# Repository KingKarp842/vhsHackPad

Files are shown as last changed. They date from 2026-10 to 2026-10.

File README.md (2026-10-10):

# vhsHackPad

This project took me around 30 hours total. It was definitely not a straight line from idea to finished macropad, but that was kind of the point. I wanted to make something more advanced than my previous macropad, and vhsHackPad ended up being a mix of PCB design, CAD, firmware, artwork, and a lot of fixing small problems that turned into bigger problems.

## Project Desc.
vhsHackPad is a custom macropad I made for VHS Hack Club. It uses a custom RP2040-based PCB, mechanical keyboard switches, USB-C, and a custom 3D printed enclosure. Instead of using a separate development board, I put the RP2040 and all the supporting parts directly onto the PCB, which made the board thinner and feel more like a real finished device.

I also wanted the PCB to be part of the design instead of something hidden inside the case. The board has custom silkscreen artwork and branding like "vhsHackPad," "Designed by Preston Nguyen," and "Made For VHS Hack Club." I also experimented with exposed ENIG/gold artwork so some of the art would show up as shiny gold on the finished PCB.

The enclosure was designed around the PCB and switches, with a slide-in style case instead of a bunch of screws. That part sounded simple at first, but the tolerances and tabs ended up taking multiple versions before they felt reasonable.

## Main Features
- Custom RP2040 PCB
- USB-C
- Mechanical keyboard switches
- Programmable macropad firmware
- Custom PCB artwork/silkscreen
- Exposed ENIG/gold decorative PCB features
- Custom CAD enclosure
- Slide-in enclosure/tabs
- 3D printed on a Bambu Lab P1S
- Designed specifically for VHS Hack Club
- JLCPCB/JLCPCB assembly-compatible PCB design

## Creation Process
1. Initial Idea & Planning
- I started vhsHackPad because I wanted to make a custom macropad specifically for VHS Hack Club. I had already made a macropad before using a XIAO RP2040, so this time I wanted to level it up by putting the RP2040 directly onto my own PCB. I also wanted the board to actually look cool and show the Hack Club/maker side of the project, not just be a plain circuit board hidden under keycaps.

2. Designing the Schematic
- I started the electronics in KiCad. I added the RP2040, USB-C, power circuitry, crystal, switches, and all the smaller supporting components that the RP2040 needs. Since I was not using a dev board this time, I had to actually understand how the chip was wired instead of just plugging into pins on a premade board.

I also added a GPIO pinout for fun because I had enough room and thought it would be cool if the macropad could technically act kind of like a dev board too, even though I would not really recommend using it that way. One of the harder parts here was figuring out the crystal and some of the RP2040 support circuitry. I had to check which crystal pins were the actual signal pins and which ones needed to be grounded. After fixing that and cleaning up a few other schematic issues, I could finally move on to the PCB layout.

vhsHackPad SCHEMATIC

3. PCB Layout & Routing
- The PCB layout was probably one of the biggest parts of the whole project. I had to place the switches, USB-C port, RP2040, flash, crystal, power parts, and a bunch of tiny components on a board that I still wanted to keep compact.

At first I kept moving the MCU around because every placement seemed to fix one problem and create another one. If the RP2040 was in one spot, the USB routing was easier but the switch traces were worse. If I moved it somewhere else, the support components fit better but routing got messy again. I probably moved the MCU back and forth way more times than I expected.

This was also my first time working with an embedded MCU directly on a board, so I had to research where the supporting components should go relative to the chip. The crystal and decoupling capacitors could not just be thrown anywhere. I had to think about keeping important parts close while still making room for the switches and artwork.

Routing was dense because there were a lot of parts fighting for space on a small board. I went through DRC multiple times while fixing clearance problems, routing issues, and unconnected pads. Eventually, I got the actual electrical design down to 0 unconnected pads, 0 footprint errors, and 0 electrical clearance violations. The remaining warnings were mostly silkscreen-related instead of real electrical problems.

vhshackpadMCU

Figuring out how to route all the parts to the MCU properly

vhsHackPadRouting

Finished Routing

vhsHackPad-nosilk

3D Render

4. Custom PCB Artwork
- I did not want the PCB to just look like a normal circuit board, so I spent a good amount of time adding custom artwork and branding. I added vhsHackPad, Designed by Preston Nguyen, Made For VHS Hack Club, the board version/date, and a bunch of Orpheus art that looked really good on the render.

The exposed copper/ENIG art was also a learning thing. I had to figure out how copper, solder mask openings, and silkscreen all interacted. Some details that looked fine on screen were too tiny to manufacture cleanly, so I had to simplify parts of the artwork and make sure it would still look decent on the real PCB.
vhsHackPadCOPPERFLAG

Copper flag art

vhsHackPad PCB

Orpheus (Hack Club Mascot) silk art!

vhsHackPad M B

3D Render w/ Silk

5. Preparing the PCB for Manufacturing
- While designing the board, I kept manufacturing and assembly in mind. I checked components and tried to pick parts that would keep the PCB reasonably inexpensive and compatible with economical PCB assembly instead of making the board way more expensive than it needed to be.

I also checked the final PCB for errors before calling it ready. This was important because once the board is manufactured, a small mistake can turn into a much more annoying problem. I made sure the important electrical issues were fixed before moving forward.
Screenshot 2026-08-14 at 11 58 27 PM

Matching Parts

vhsHackPadJLCBack

vhsHackPadJLCFront

Render of the pcb (obviously in black)

6. Designing the Enclosure
- Once the PCB was mostly finished, I started designing the enclosure. I used measurements from my previous macropad as a starting point because I already had a rough idea of what worked and what did not.

For this version, I made the switch openings around 15.75 mm x 15.75 mm because I did not want the switches to clip in too tightly. I wanted the build to be removable enough that the board could still be accessed. I also had to balance the spacing between the switches and the case edges so it stayed compact without making everything cramped.

7. Fixing Switch & Case Clearances
- Some of the original CAD dimensions looked fine in SolidWorks but were too tight for real 3D printing. That was one of the bigger lessons from the enclosure: if two parts are modeled with basically no tolerance, they are probably not going to slide together nicely after printing.

I had to go back and resize the switch openings, spacing, and walls. The slide-in tabs especially needed adjustments because the first versions were either too tight or just not practical. I went through about 4 versions of the enclosure, changing a measurement, checking what it affected, and then changing nearby features too.

8. Designing the Slide-In Case
- I wanted the enclosure pieces to slide together instead of using a bunch of screws, so I designed small slide-in tabs with matching openings. This ended up being way more annoying than I expected.

Originally, some of the tabs and openings were around 0.60 mm and 0.75 mm, but that was too close for 3D printing. A tab that is the same size as the slot in CAD does not magically fit perfectly in real life. I experimented with smaller tab dimensions, including around 0.45 mm for a 0.60 mm opening, so there would actually be some clearance.

The goal was to make the case tight enough that it would not randomly fall apart, but loose enough that it could still slide together without feeling like I was about to break it. This part took a lot of tiny edits.

A388B26B-A696-4B3C-B306-50D3C65838B8_1_105_c

71BBC9EB-22AC-4D64-BC14-521CB4A789E4_1_105_c

B477437C-3D49-40A2-884D-C89541A27FF9_1_105_c

Solidworks Crashed alot... also lapse didn't work on all of CAD...

9. Iterating the CAD
- A lot of the CAD process was basically fixing one thing and then realizing that the fix affected something else. Changing the tabs affected the nearby walls. Changing wall thickness affected how much space the PCB had. Changing clearances affected whether the slide-in case felt usable.

For example, when I changed dimensions from around 0.75 mm to 0.60 mm, I also had to adjust distances between those features and the walls. It was not just one magic number that fixed everything. I had to keep checking the whole case as one system.

SolidWorks also crashed a lot, which made the process more frustrating because I could not always just smoothly iterate. Still, after enough versions, the enclosure ended up in a much better place than the first model.

A8300315-275C-4646-8056-96588B22744A_1_105_c

Top View of Finished CAD

2E81ADBB-D204-44F5-8050-76056BB91F5F_1_105_c

FINISHED CAD

10. Final Hardware Design
- After the electronics, PCB layout, artwork, enclosure, and tolerance work, I ended up with a complete vhsHackPad design. This was a big step up from my previous macropad because I was no longer building around a premade RP2040 board. I designed the RP2040 electronics into the PCB myself, which made the final build cleaner and more complete.

The manufactured PCB honestly came out really nice, especially the artwork. The enclosure and acrylic were less perfect. I used score-and-snap for the acrylic, and one of the corners did not snap cleanly along the line. The top-left corner ended up looking kind of ugly because I rushed it and did not support/snap it as carefully as I should have. It still works, but it is definitely a visible reminder that the physical build matters just as much as the CAD.

B6525CCC-FC3B-416D-AB25-DD14E9A96C1E_1_105_c

Manufactured PCB! (IT LOOKS SO GOOD YAYY)

528901A4-0872-4D8E-BF5D-6395DE8F3A71_1_102_o

A22F3DD4-4E69-48C5-B66F-BC39F1697796_1_105_c

I was scoring and snapping the acrylic and got lazy so the top left is snapped weird

52E2D442-2B58-433F-9D02-B933B688B8AD_1_105_c

Final Assembled Build

11. Programming the HackPad
- After the hardware was designed, I worked on the firmware that makes the HackPad act like a keyboard. I used CircuitPython with KMK to program the RP2040 and assign actions to the mechanical switches.

This also needed multiple updates instead of working perfectly the first time. I had to make sure the switch pins in the firmware matched the GPIO pins I chose in the PCB design. Since the PCB was custom, the code had to match my actual hardware layout, not some default macropad layout from online.

The firmware is easy to change later, so the keys can be remapped to different shortcuts or functions without changing the hardware. That was one of the reasons I wanted to use KMK/CircuitPython in the first place.

12. Testing & Iterating the Firmware
- Once the firmware was on the board, I tested the switches to make sure each key press was detected and sent the expected keyboard input over USB. Some things needed fixing. One of the main bugs was that the left and right arrow keys were backwards, so pressing the physical left key would act like right, and pressing the right key would act like left.

To fix it, I had to compare the code against the actual PCB pin assignments and key layout, then update the keymap so the physical keys matched what they were supposed to do. I also updated the firmware multiple times while testing different key assignments and making sure the macropad behaved like a normal USB keyboard.

This part reminded me that a PCB can be electrically fine and still need software debugging. The code running is not the same thing as every key doing the correct thing.

Check out the CODE README under the Firmware section!

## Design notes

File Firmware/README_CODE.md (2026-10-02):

# Firmware

The macropad runs on CircuitPython and uses the adafruit_hid library to act like a USB keyboard.
The four switches are connected directly to GPIO pins on the RP2040:
- GPIO2 = Up
- GPIO3 = Left
- GPIO4 = Down
- GPIO5 = Right

By default, the macropad works as a normal arrow-key pad.
It also has a second shortcut mode. To switch modes, press all three bottom keys at the same time, release them, and repeat that 3 times within about 2 seconds.

## Arrow Mode

- Top = Up Arrow
- Bottom Left = Left Arrow
- Bottom Middle = Down Arrow
- Bottom Right = Right Arrow

## Shortcut Mode

- Top = Command + Tab
- Bottom Left = Command + T
- Bottom Middle = Command + V
- Bottom Right = Command + C
Pressing the bottom three keys together 3 times again switches back to arrow mode.

## How the Code Works

Each switch is set up as a digital input with the RP2040's internal pull-up resistor enabled. Because each switch connects the GPIO pin to ground when pressed, the code treats a LOW signal as a key press. The program constantly checks the state of all four switches. When a key changes from released to pressed, it sends the matching keyboard command over USB using adafruit_hid.

The code also watches for the three bottom keys being pressed at the same time. Each completed three-key press counts toward the mode-change sequence. After three of these presses, the firmware switches between arrow mode and shortcut mode.

## Setting Up the Board

The RP2040 first needs CircuitPython installed.
Hold the BOOTSEL button while plugging the board into a computer. The board should appear as a drive called:
RPI-RP2
Download the correct CircuitPython .uf2 file for the RP2040 and copy it onto RPI-RP2.
After the board restarts, it should appear as:
CIRCUITPY

## Installing the HID Library

The firmware uses Adafruit's HID library.
Download the CircuitPython Library Bundle that matches the major version of CircuitPython installed on the board.
From the bundle, copy:
adafruit_hid
into the lib folder on the board.

## Installing the Firmware

Copy the macropad firmware into the root of the CIRCUITPY drive and name it:
code.py

CircuitPython automatically runs code.py whenever the board powers on or the file is saved.
No separate compiler or flashing software is needed after CircuitPython is installed.

The current shortcut layout is made for macOS because it uses the Command key for copy, paste, new tab, and application switching.

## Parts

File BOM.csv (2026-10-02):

Item | Quantity | Description
Custom PCB | 1 | RP2040 macropad PCB with all SMD components assembled
MX-Compatible Keyswitch | 4 | User-installed keyboard switches
Keycaps | 4 | MX-compatible keycaps
Acrylic Bottom | 1 | Clear acrylic bottom panel
3D Printed Case | 1 | Custom enclosure
USB-C Cable | 1 | For power and data

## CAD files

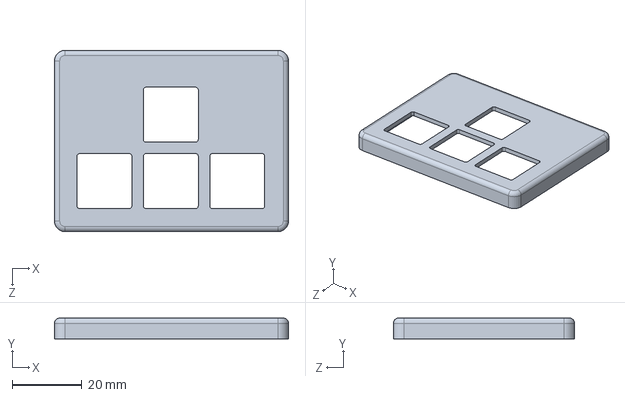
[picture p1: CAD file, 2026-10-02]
CAD Files/SolidWorks/vhsHackPad_Top.SLDPRT
67.1 x 6.00 x 52.0 mm

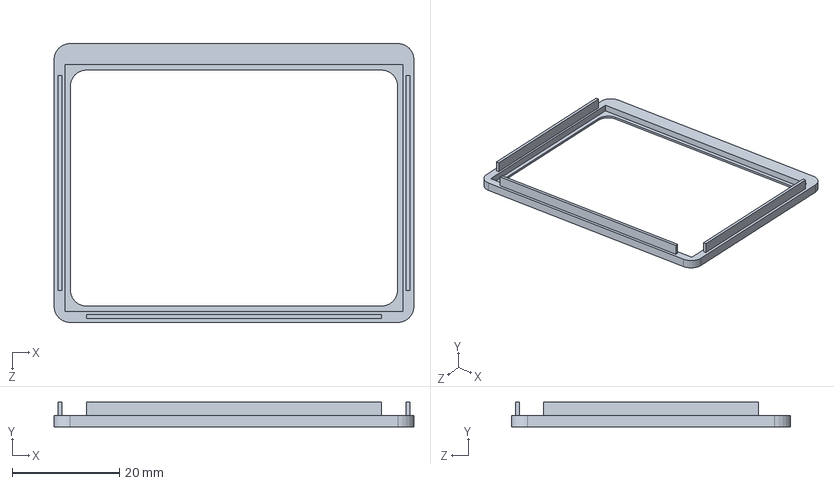
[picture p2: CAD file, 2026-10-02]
CAD Files/SolidWorks/vhsHackPad_Bottom.SLDPRT
67.1 x 4.60 x 52.0 mm

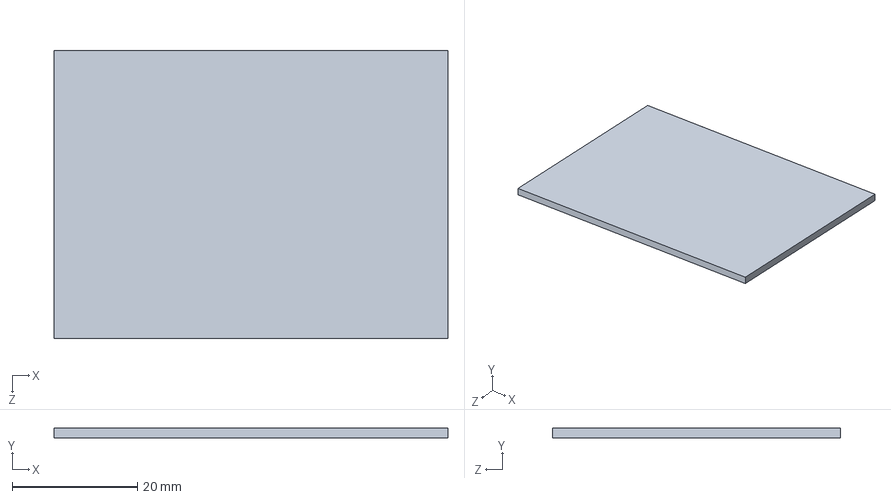
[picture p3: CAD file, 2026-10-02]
CAD Files/SolidWorks/vhsHackPad_Acrylic.SLDPRT
63.0 x 1.60 x 46.0 mm

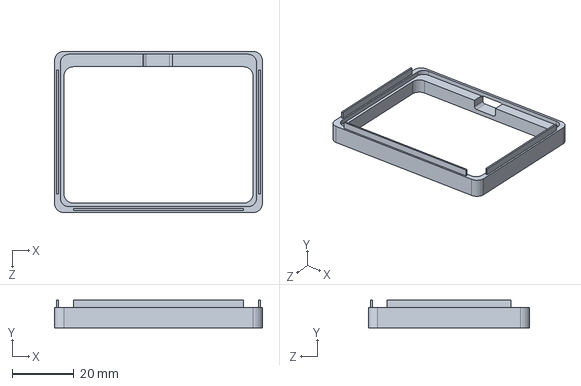
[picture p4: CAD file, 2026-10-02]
CAD Files/SolidWorks/vhsHackPad_Middle.SLDPRT
67.1 x 9.00 x 52.0 mm

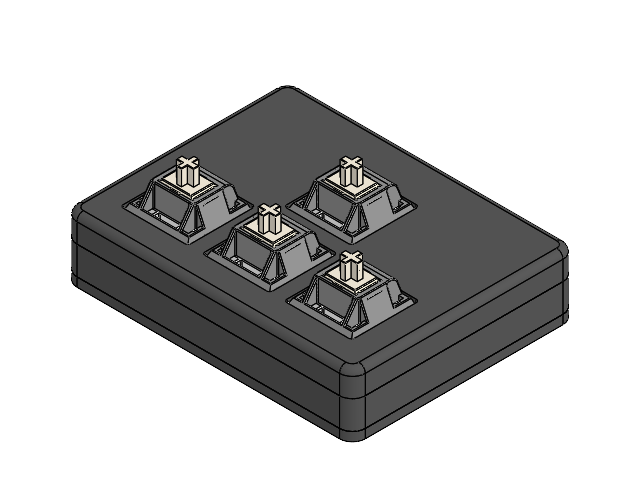
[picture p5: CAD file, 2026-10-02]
CAD Files/SolidWorks/vhsHackPad_Assembly.SLDASM
vhsHackPad_Bottom
vhsHackPad_Middle
vhsHackPad_Top
C_0603_1608Metric-0.step x 17
R_0603_1608Metric-1.step x 6
SW_SPST_TL3305A-2.step x 2
QFN-56-1EP_7x7mm_P0.4mm_EP3.2x3.2mm-3.step
SOIC-8_5.3x5.3mm_P1.27mm-4.step
Crystal_SMD_3225-4Pin_3.2x2.5mm-5.step
SOT-23-5-6.step
vhsHackPad_copper.step
vhsHackPad_silkscreen-7.step
vhsHackPad_soldermask.step
vhsHackPad_soldermask-8.step
vhsHackPad_PCB.step
f69c03da-2874-4e90-9b88-dd8424af37a8.step
vhsHackPad_Acrylic
MX_DOWN.stp x 4
MX_UP.stp x 4
UP_MX.stp x 4
MX_PIN.stp x 4
MX_SPRING.stp x 4
MX_CLICK.stp x 4

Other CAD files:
CAD Files/3MF/vhsHackPad_Bottom.3MF
CAD Files/3MF/vhsHackPad_Middle.3MF
CAD Files/3MF/vhsHackPad_Top.3MF

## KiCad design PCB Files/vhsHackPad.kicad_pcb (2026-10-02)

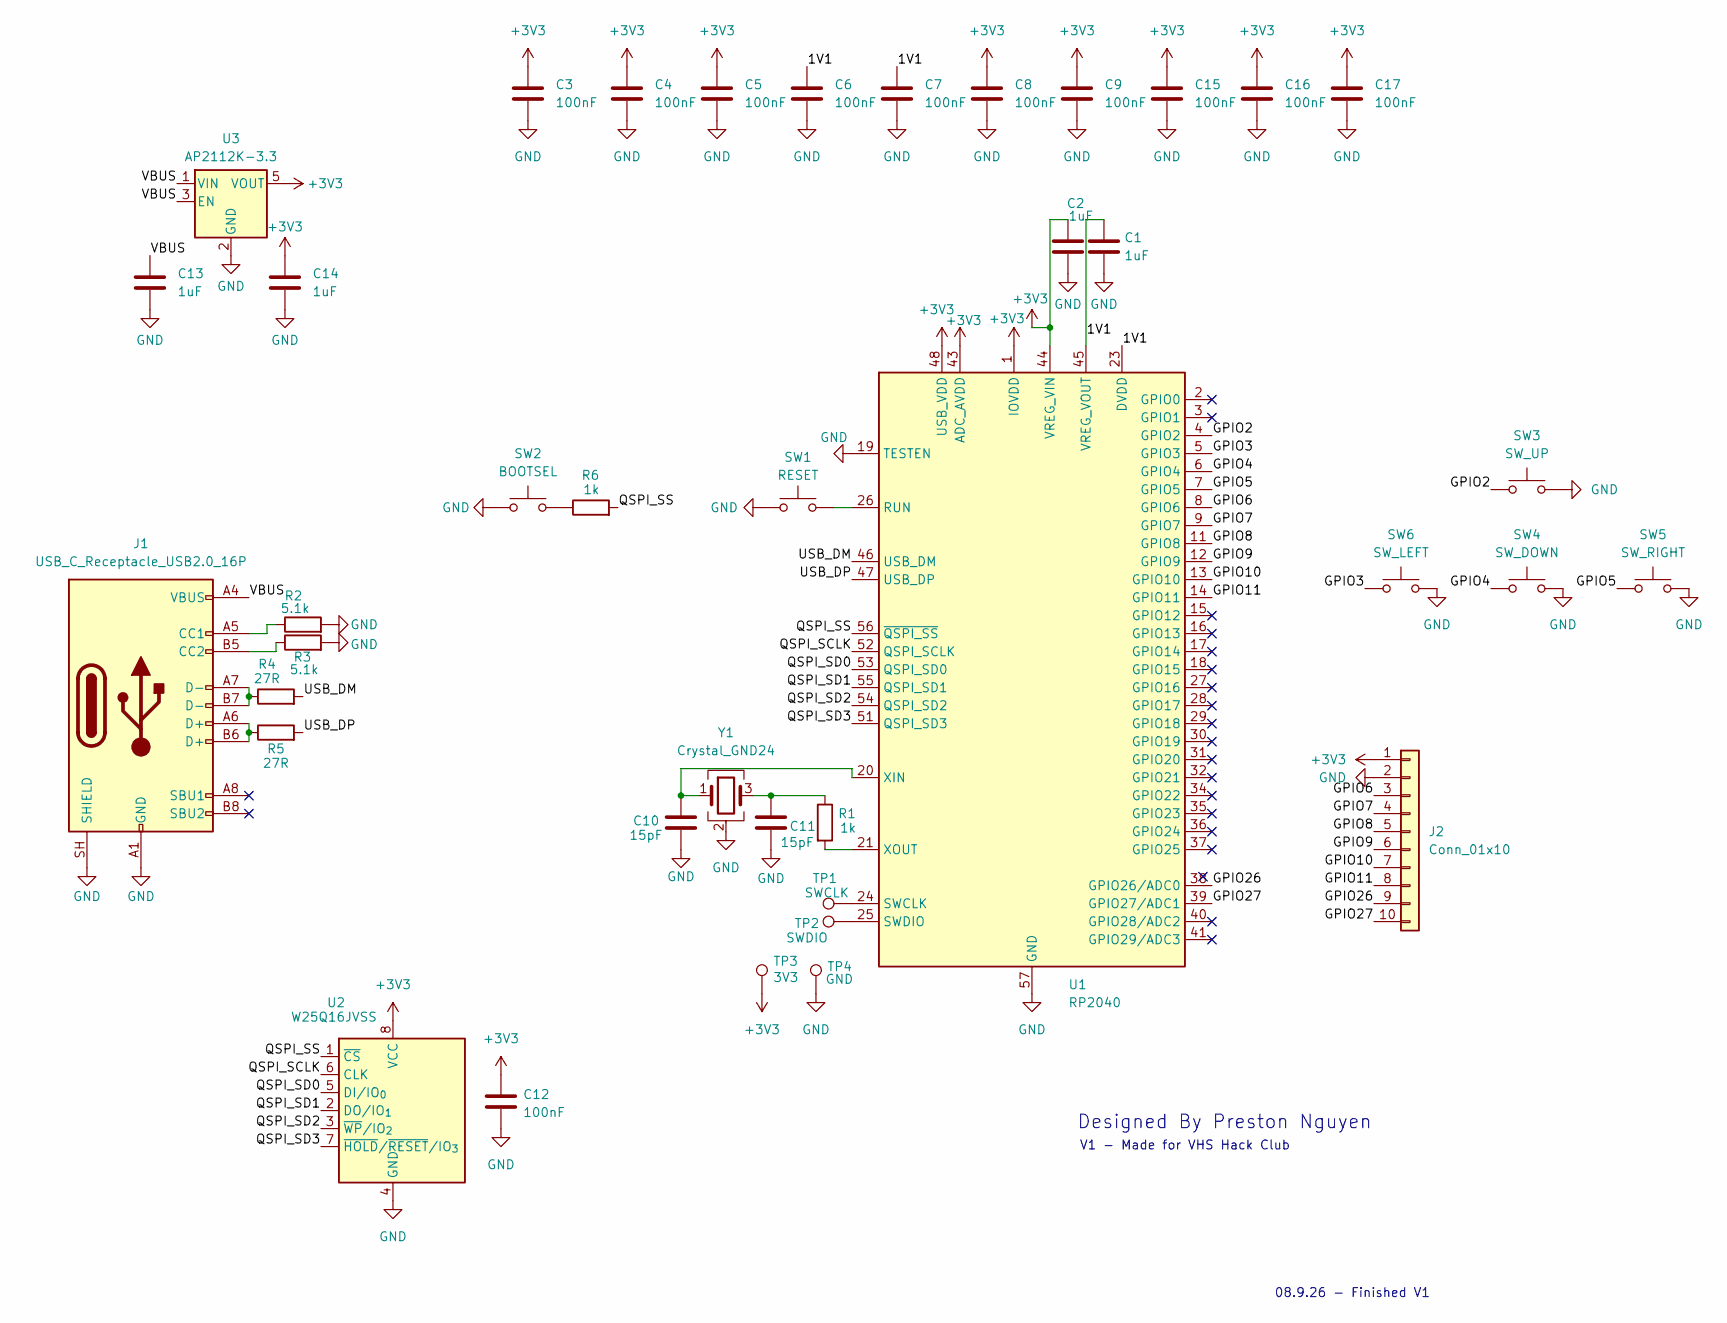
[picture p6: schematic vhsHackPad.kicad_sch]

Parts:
C1, C2, C13, C14: 1uF; C_0603_1608Metric
C3, C4, C5, C6, C7, C8, C9, C12, C15, C16, C17: 100nF; C_0603_1608Metric
C10, C11: 15pF; C_0603_1608Metric
J1: USB_C_Receptacle_USB2.0_16P; USB_C_Receptacle_HRO_TYPE-C-31-M-12
J2: Conn_01x10; PinHeader_1x10_P2.54mm_Vertical
R1, R6: 1k; R_0603_1608Metric
R2, R3: 5.1k; R_0603_1608Metric
R4, R5: 27R; R_0603_1608Metric
SW1: RESET; SW_SPST_TL3305A
SW2: BOOTSEL; SW_SPST_TL3305A
SW3: SW_UP; SW_Cherry_MX_1.00u_PCB
SW4: SW_DOWN; SW_Cherry_MX_1.00u_PCB
SW5: SW_RIGHT; SW_Cherry_MX_1.00u_PCB
SW6: SW_LEFT; SW_Cherry_MX_1.00u_PCB
TP1: SWCLK; TestPoint_Pad_D1.5mm
TP2: SWDIO; TestPoint_Pad_D1.5mm
TP3: 3V3; TestPoint_Pad_D1.5mm
TP4: GND; TestPoint_Pad_D1.5mm
U1: RP2040; QFN-56-1EP_7x7mm_P0.4mm_EP3.2x3.2mm
U2: W25Q16JVSS; SOIC-8_5.3x5.3mm_P1.27mm
U3: AP2112K-3.3; SOT-23-5
Y1: Crystal_GND24; Crystal_SMD_3225-4Pin_3.2x2.5mm

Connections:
+3V3: C2.1, C3.1, C4.1, C5.1, C8.1, C9.1, C12.1, C14.1, C15.1, C16.1, C17.1, J2.1, TP3.1 (1_1), U1.1 (IOVDD), U1.10 (IOVDD), U1.22 (IOVDD), U1.33 (IOVDD), U1.42 (IOVDD), U1.43 (ADC_AVDD), U1.44 (VREG_VIN), U1.48 (USB_VDD), U1.49 (IOVDD), U2.8 (VCC), U3.5 (VOUT)
/1V1: C1.1, C6.1, C7.1, U1.23 (DVDD), U1.45 (VREG_VOUT), U1.50 (DVDD)
/GPIO2: SW3.1, U1.4 (GPIO2)
/GPIO3: SW6.1, U1.5 (GPIO3)
/GPIO4: SW4.1, U1.6 (GPIO4)
/GPIO5: SW5.1, U1.7 (GPIO5)
/GPIO6: J2.3, U1.8 (GPIO6)
/GPIO7: J2.4, U1.9 (GPIO7)
/GPIO8: J2.5, U1.11 (GPIO8)
/GPIO9: J2.6, U1.12 (GPIO9)
/GPIO10: J2.7, U1.13 (GPIO10)
/GPIO11: J2.8, U1.14 (GPIO11)
/GPIO26: J2.9, U1.38 (GPIO26/ADC0)
/GPIO27: J2.10, U1.39 (GPIO27/ADC1)
/QSPI_SCLK: U1.52 (QSPI_SCLK), U2.6 (CLK)
/QSPI_SD0: U1.53 (QSPI_SD0), U2.5 (DI/IO_{0})
/QSPI_SD1: U1.55 (QSPI_SD1), U2.2 (DO/IO_{1})
/QSPI_SD2: U1.54 (QSPI_SD2), U2.3 (~WP/IO_{2})
/QSPI_SD3: U1.51 (QSPI_SD3), U2.7 (~HOLD/~RESET/IO_{3})
/QSPI_SS: R6.2, U1.56 (~QSPI_SS), U2.1 (~CS)
/USB_DM: R4.2, U1.46 (USB_DM)
/USB_DP: R5.2, U1.47 (USB_DP)
/VBUS: C13.1, J1.A4 (VBUS), J1.A9 (VBUS), J1.B4 (VBUS), J1.B9 (VBUS), U3.1 (VIN), U3.3 (EN)
GND: C1.2, C2.2, C3.2, C4.2, C5.2, C6.2, C7.2, C8.2, C9.2, C10.2, C11.2, C12.2, C13.2, C14.2, C15.2, C16.2, C17.2, J1.A1 (GND), J1.A12 (GND), J1.B1 (GND), J1.B12 (GND), J1.SH (SHIELD), J2.2, R2.2, R3.2, SW1.1, SW2.1, SW3.2, SW4.2, SW5.2, SW6.2, TP4.1 (1_1), U1.19 (TESTEN), U1.57 (GND), U2.4 (GND), U3.2 (GND), Y1.2 (G), Y1.4 (G)
unnamed: C11.1, R1.1, Y1.3
unnamed: J1.A5 (CC1), R2.1
unnamed: J1.B5 (CC2), R3.1
unnamed: J1.A6 (D+), J1.B6 (D+), R5.1
unnamed: J1.A7 (D-), J1.B7 (D-), R4.1
unnamed: R6.1, SW2.2
unnamed: SW1.2, U1.26 (RUN)
unnamed: TP1.1 (1_1), U1.24 (SWCLK)
unnamed: TP2.1 (1_1), U1.25 (SWDIO)
unnamed: C10.1, U1.20 (XIN), Y1.1
unnamed: R1.2, U1.21 (XOUT)

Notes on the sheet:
08.9.26 - Finished V1
V1 - Made for VHS Hack Club
Designed By Preston Nguyen

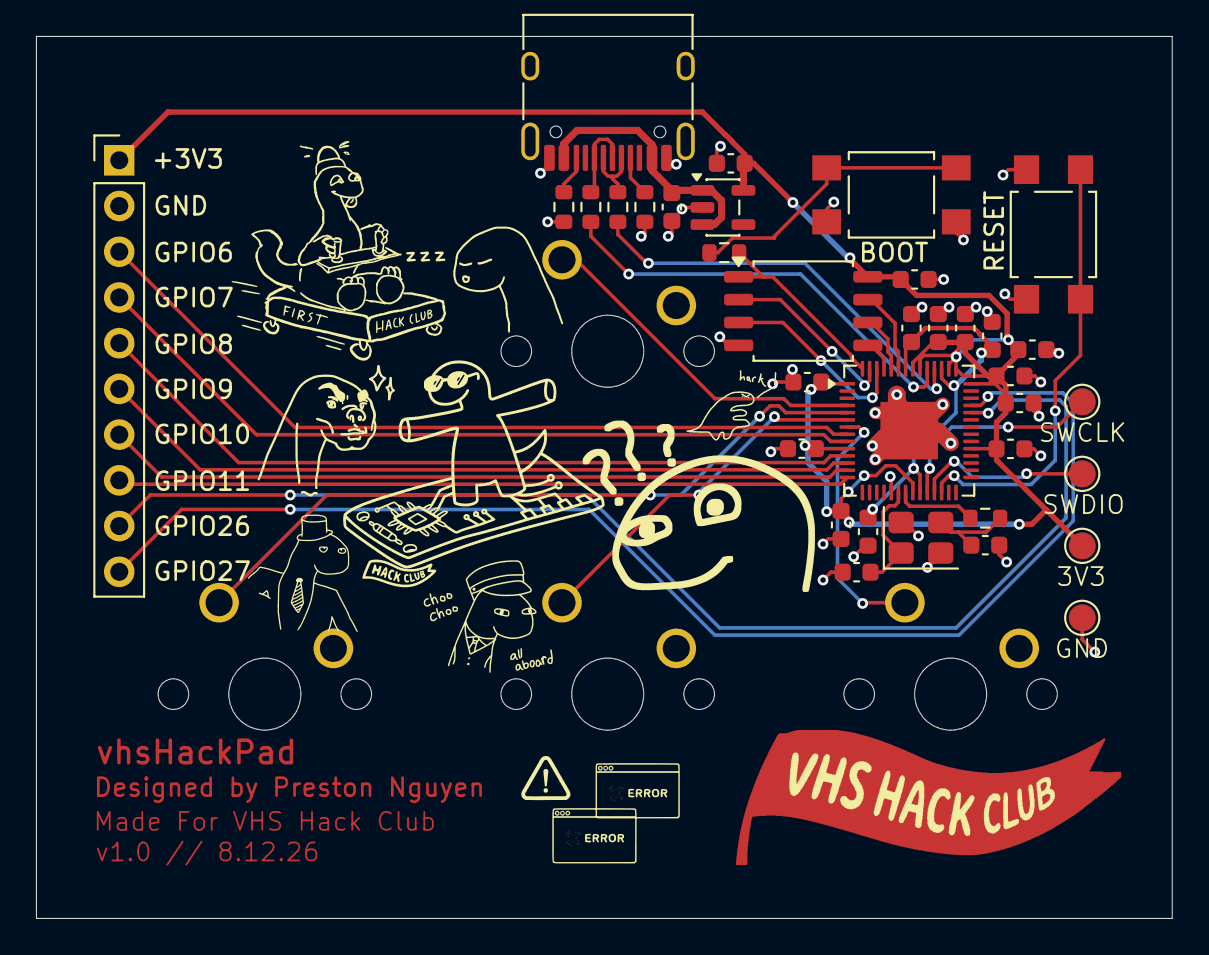
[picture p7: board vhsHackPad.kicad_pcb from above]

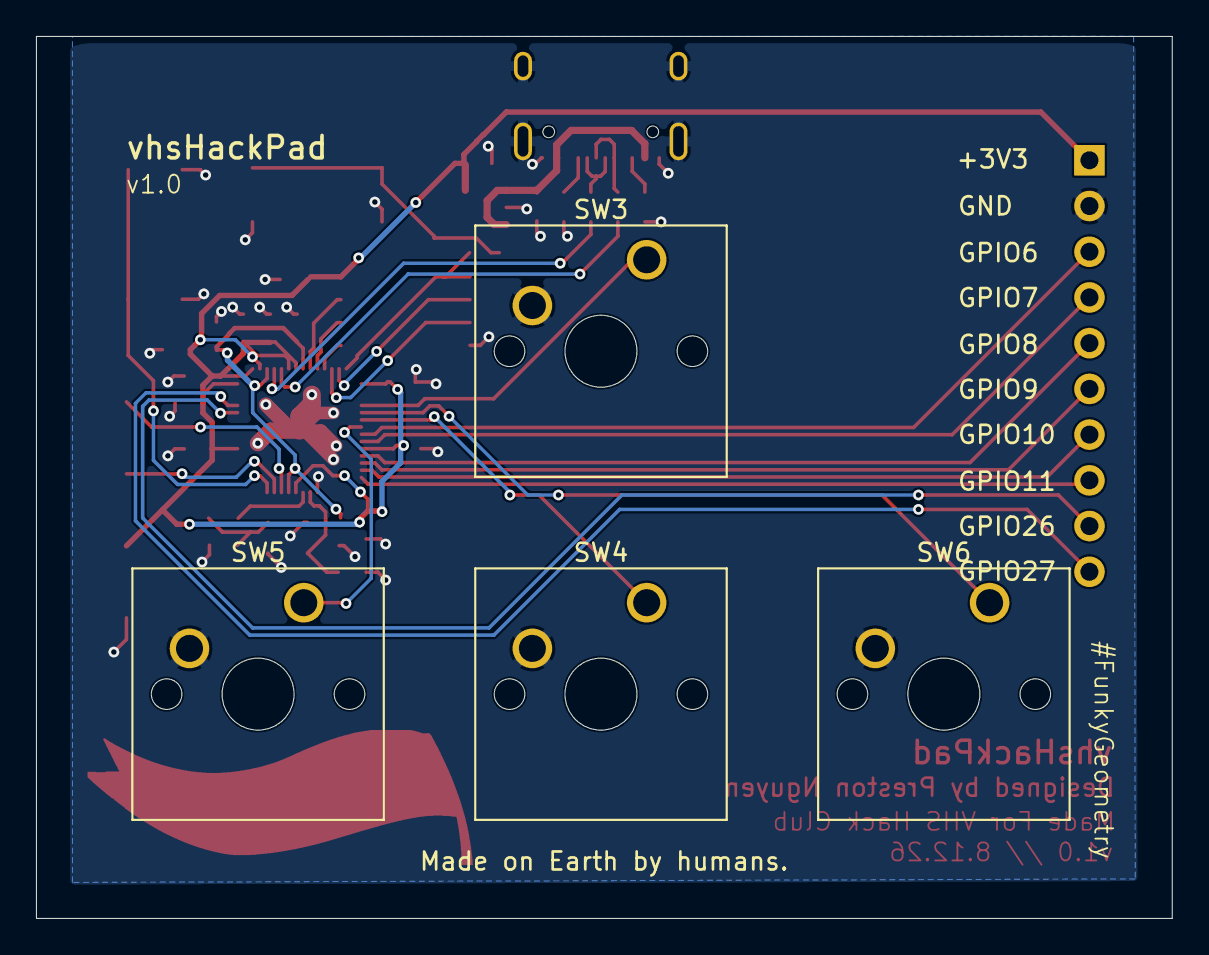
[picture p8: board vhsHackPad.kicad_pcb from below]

Board: 2 copper layers, 63.1 x 49.0 mm, 39 parts (4 on the bottom side), 35 nets.

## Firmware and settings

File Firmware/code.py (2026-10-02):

import time
import board
import digitalio
import usb_hid

from adafruit_hid.keyboard import Keyboard
from adafruit_hid.keycode import Keycode

UP = board.GP2
LEFT = board.GP3
DOWN = board.GP4
RIGHT = board.GP5

def setup_button(pin):
    b = digitalio.DigitalInOut(pin)
    b.direction = digitalio.Direction.INPUT
    b.pull = digitalio.Pull.UP
    return b

up = setup_button(UP)
left = setup_button(LEFT)
down = setup_button(DOWN)
right = setup_button(RIGHT)

keyboard = Keyboard(usb_hid.devices)

shortcut_mode = False
combo_count = 0
last_combo = 0
combo_held = False

prev = {
    "up": False,
    "left": False,
    "down": False,
    "right": False
}

def is_pressed(button):
    return not button.value

def press_key(name):
    if shortcut_mode:
        if name == "up":
            keyboard.send(Keycode.COMMAND, Keycode.TAB)
        elif name == "left":
            keyboard.send(Keycode.COMMAND, Keycode.T)
        elif name == "down":
            keyboard.send(Keycode.COMMAND, Keycode.V)
        elif name == "right":
            keyboard.send(Keycode.COMMAND, Keycode.C)
    else:
        if name == "up":
            keyboard.send(Keycode.UP_ARROW)
        elif name == "left":
            keyboard.send(Keycode.LEFT_ARROW)
        elif name == "down":
            keyboard.send(Keycode.DOWN_ARROW)
        elif name == "right":
            keyboard.send(Keycode.RIGHT_ARROW)

while True:
    now = time.monotonic()

    current = {
        "up": is_pressed(up),
        "left": is_pressed(left),
        "down": is_pressed(down),
        "right": is_pressed(right)
    }

    combo = current["left"] and current["down"] and current["right"]

    if combo and not combo_held:
        combo_held = True

        if now - last_combo > 2:
            combo_count = 0

        combo_count += 1
        last_combo = now

        if combo_count == 3:
            shortcut_mode = not shortcut_mode
            combo_count = 0
            print("shortcut" if shortcut_mode else "arrows")

    if not combo:
        combo_held = False

    if not combo:
        for key in current:
            if current[key] and not prev[key]:
                press_key(key)

    prev = current.copy()
    time.sleep(0.01)
